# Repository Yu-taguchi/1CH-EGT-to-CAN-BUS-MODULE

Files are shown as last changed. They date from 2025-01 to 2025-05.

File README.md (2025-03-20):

# 1CH EGT TO CAN BUS モジュール

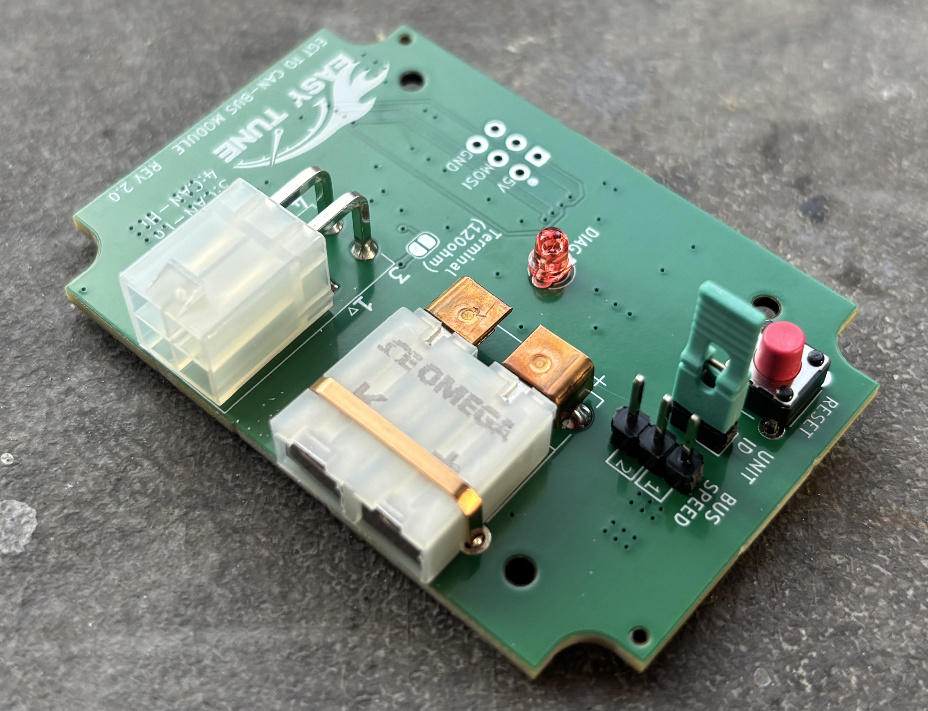
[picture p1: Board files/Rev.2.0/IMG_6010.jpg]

これは 1 チャンネル EGT ボードです。
このボードは、アフター製 エンジン コントロール ユニットと組み合わせて使用し、排気ガス温度を測定することを目的としています。
PCB は、1つの MAX31855 チップと ATMEGA328P に基づいています。
使用するセンサーは、ミニ K タイプ サーモカップル コネクタを備えた K タイプ EGT センサーである必要があります。

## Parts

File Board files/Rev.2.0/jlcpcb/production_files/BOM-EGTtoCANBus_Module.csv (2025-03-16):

Comment | Designator | Footprint | LCSC
8MHz | Y2 | Crystal_SMD_5032-2Pin_5.0x3.2mm | C115962
10uF | C4,C5,C6,C7 | C_1206_3216Metric | C13585
16MHz | Y3 | Crystal_SMD_3225-4Pin_3.2x2.5mm | C13738
ATmega328P-A | U1 | TQFP-32_7x7mm_P0.8mm | C14877
10k | R2,R3,R6 | R_0805_2012Metric | C17414
120 | R1 | R_0805_2012Metric | C17437
1k | R5,R7 | R_0805_2012Metric | C17513
22pF | C10,C12,C13,C9 | C_0805_2012Metric | C1804
1N4148WS | D2,D4 | D_SOD-323 | C2128
LED | D1,D5 | LED_D3.0mm | C2297
0.1uF | C1,C11,C2,C3,C8 | C_0805_2012Metric | C49678
MAX31855KASA | U7 | SOIC-8_3.9x4.9mm_P1.27mm | C52028
TJA1044T | U9 | SOIC-8_3.9x4.9mm_P1.27mm | C520388
MCP2515-I | U2 | TSSOP-20_4.4x6.5mm_P0.65mm | C5250735
AMS1117-3.3 | U5 | SOT-223-3_TabPin2 | C6186
AMS1117-5.0 | U3 | SOT-223-3_TabPin2 | C6187
D_Schottky | D3 | D_SOD-123 | C8598
Jumper_2_Open | JP3 | PinSocket_1x02_P2.54mm_Vertical
Jumper_3_Open | JP2 | PinSocket_1x03_P2.54mm_Vertical
SolderJumper | JP1 | SolderJumper-2_P1.3mm_Open_RoundedPad1.0x1.5mm
39-30-1040 | J2 | MOLEX_39-30-1040
PCC-SMP-V-K-5 | J3 | OMEGA_PCC-SMP-K-5
AVR-ISP-6 | J1 | IDC-Header_2x03_P2.54mm_Vertical

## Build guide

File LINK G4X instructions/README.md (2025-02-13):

# Instructions for LINK G4X
CAN設定画面を開き、下記の通りに設定すること。  
フレームデータファイル(.lcs)を用意しているので、こちらを読み込む事も可。

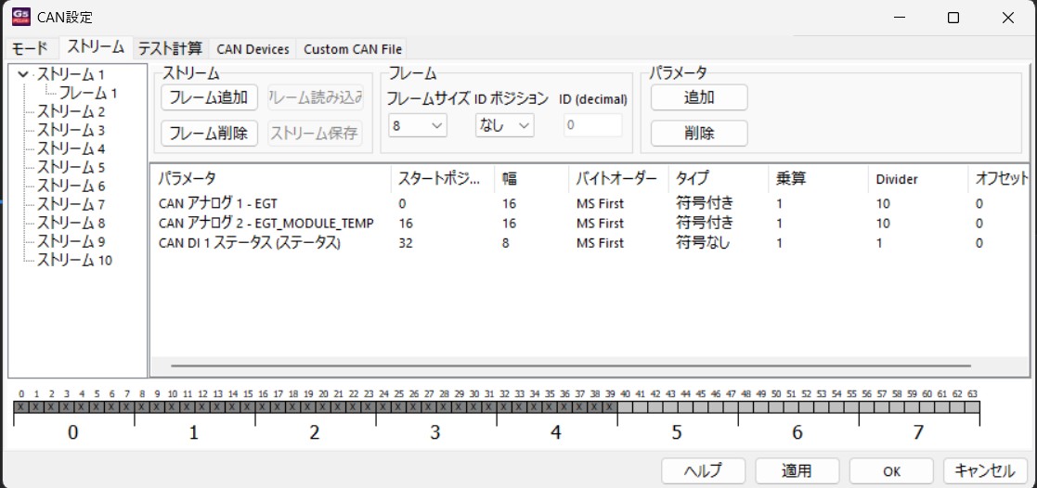
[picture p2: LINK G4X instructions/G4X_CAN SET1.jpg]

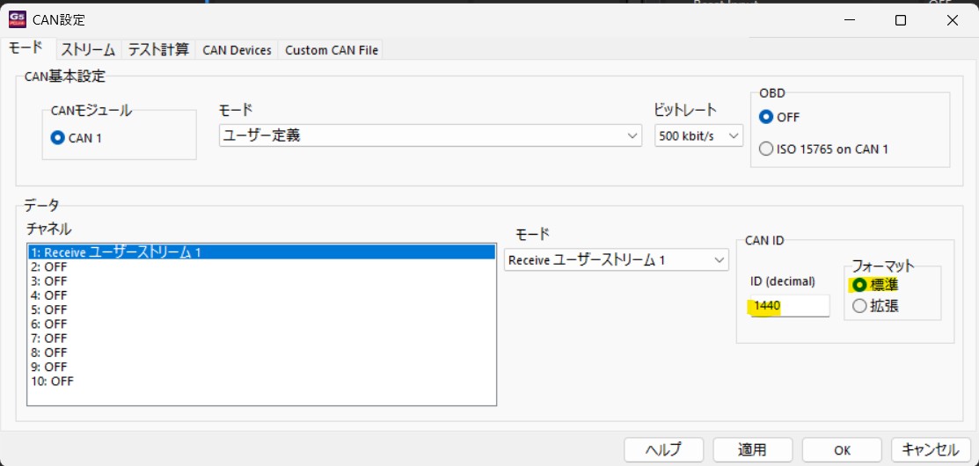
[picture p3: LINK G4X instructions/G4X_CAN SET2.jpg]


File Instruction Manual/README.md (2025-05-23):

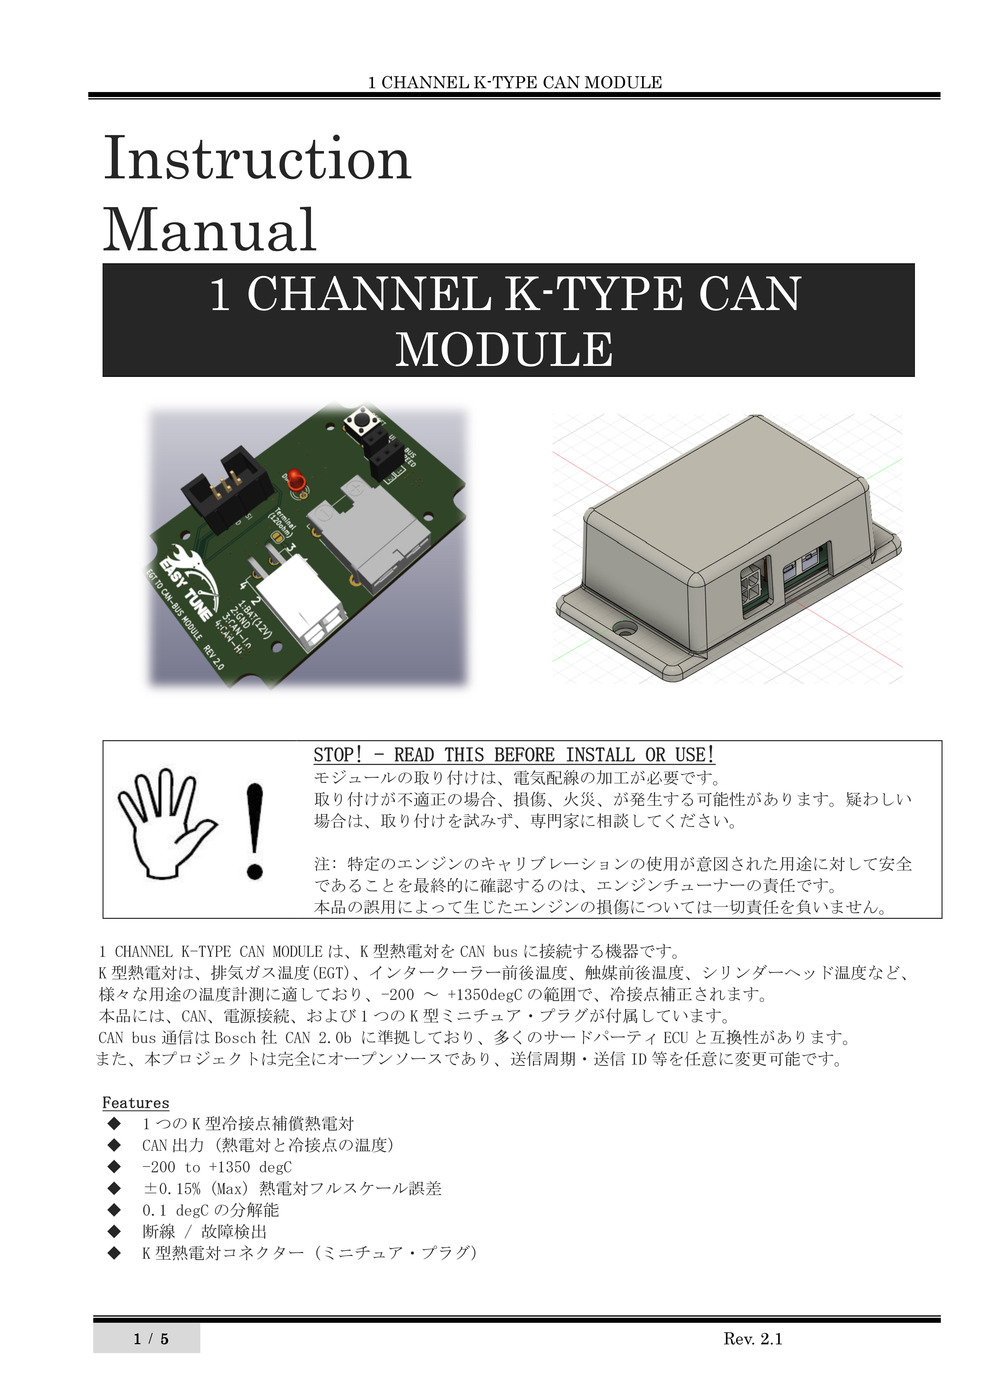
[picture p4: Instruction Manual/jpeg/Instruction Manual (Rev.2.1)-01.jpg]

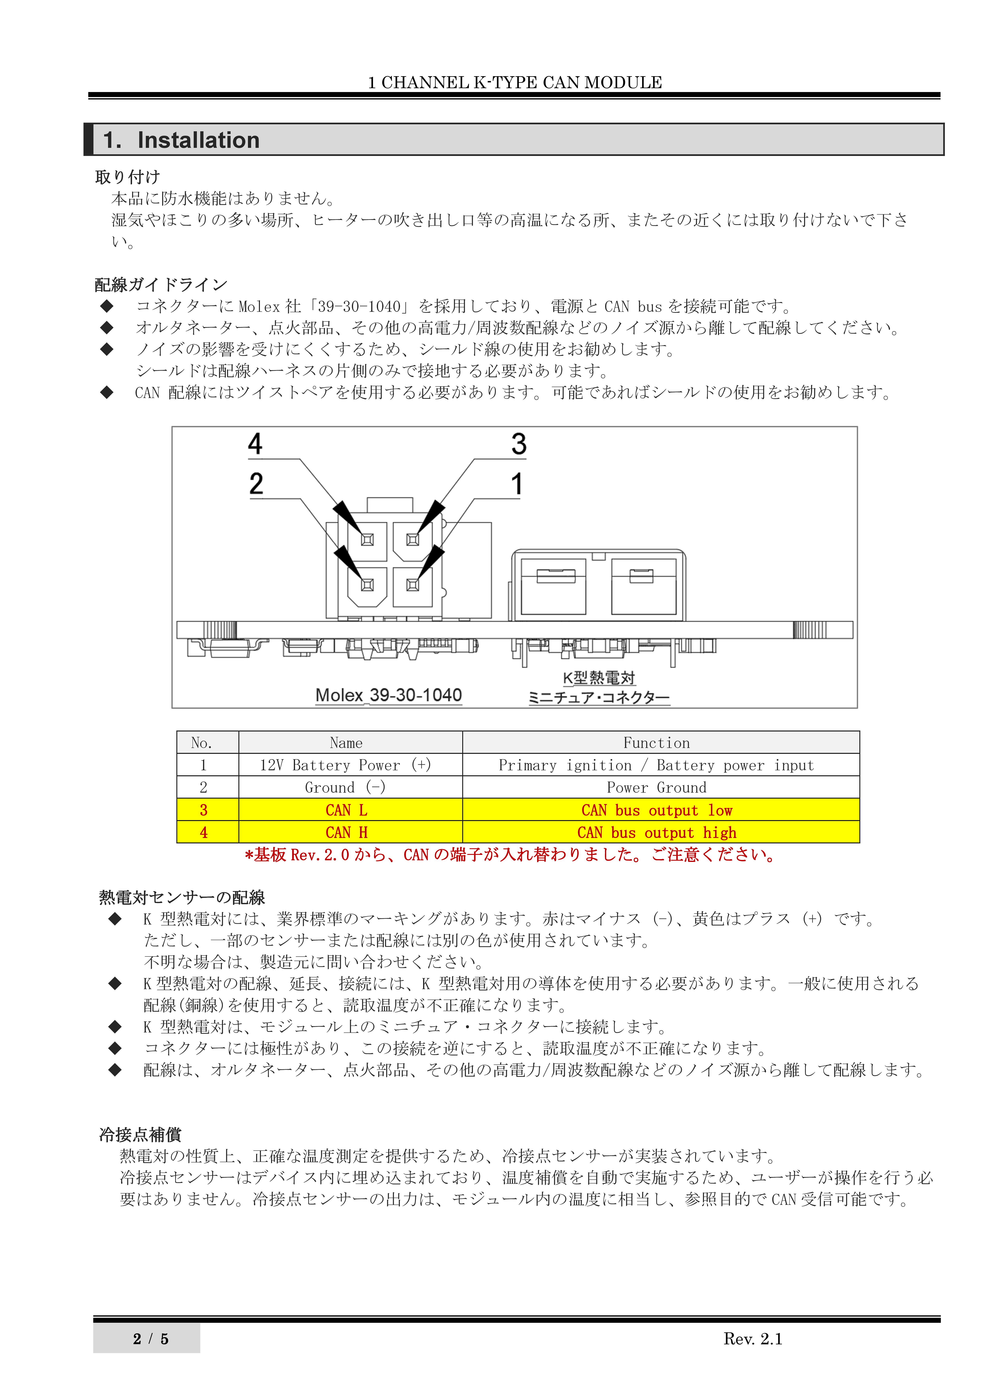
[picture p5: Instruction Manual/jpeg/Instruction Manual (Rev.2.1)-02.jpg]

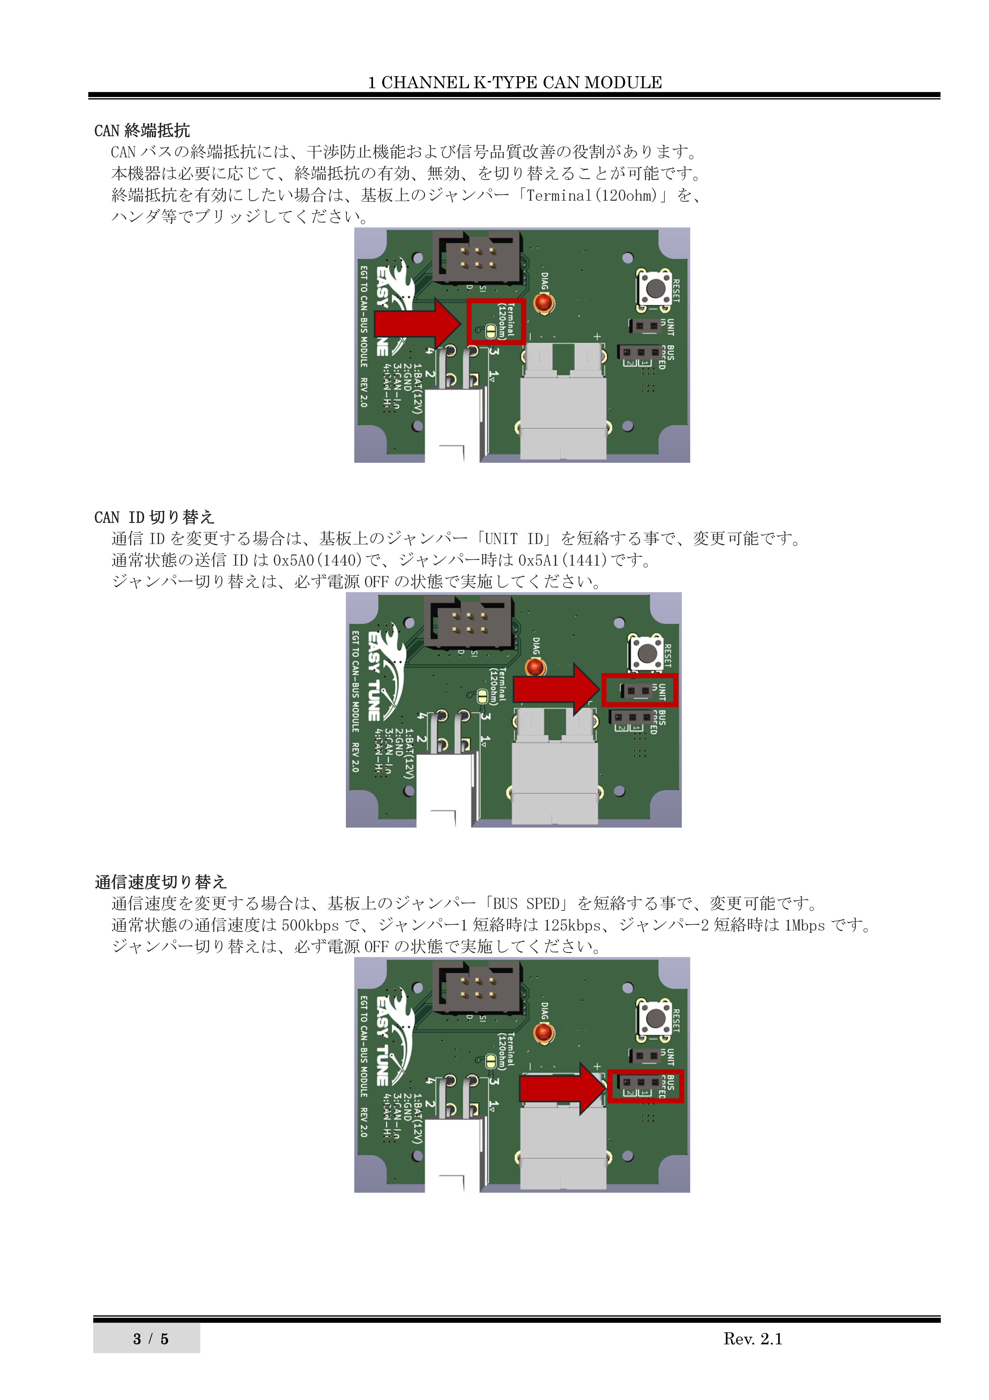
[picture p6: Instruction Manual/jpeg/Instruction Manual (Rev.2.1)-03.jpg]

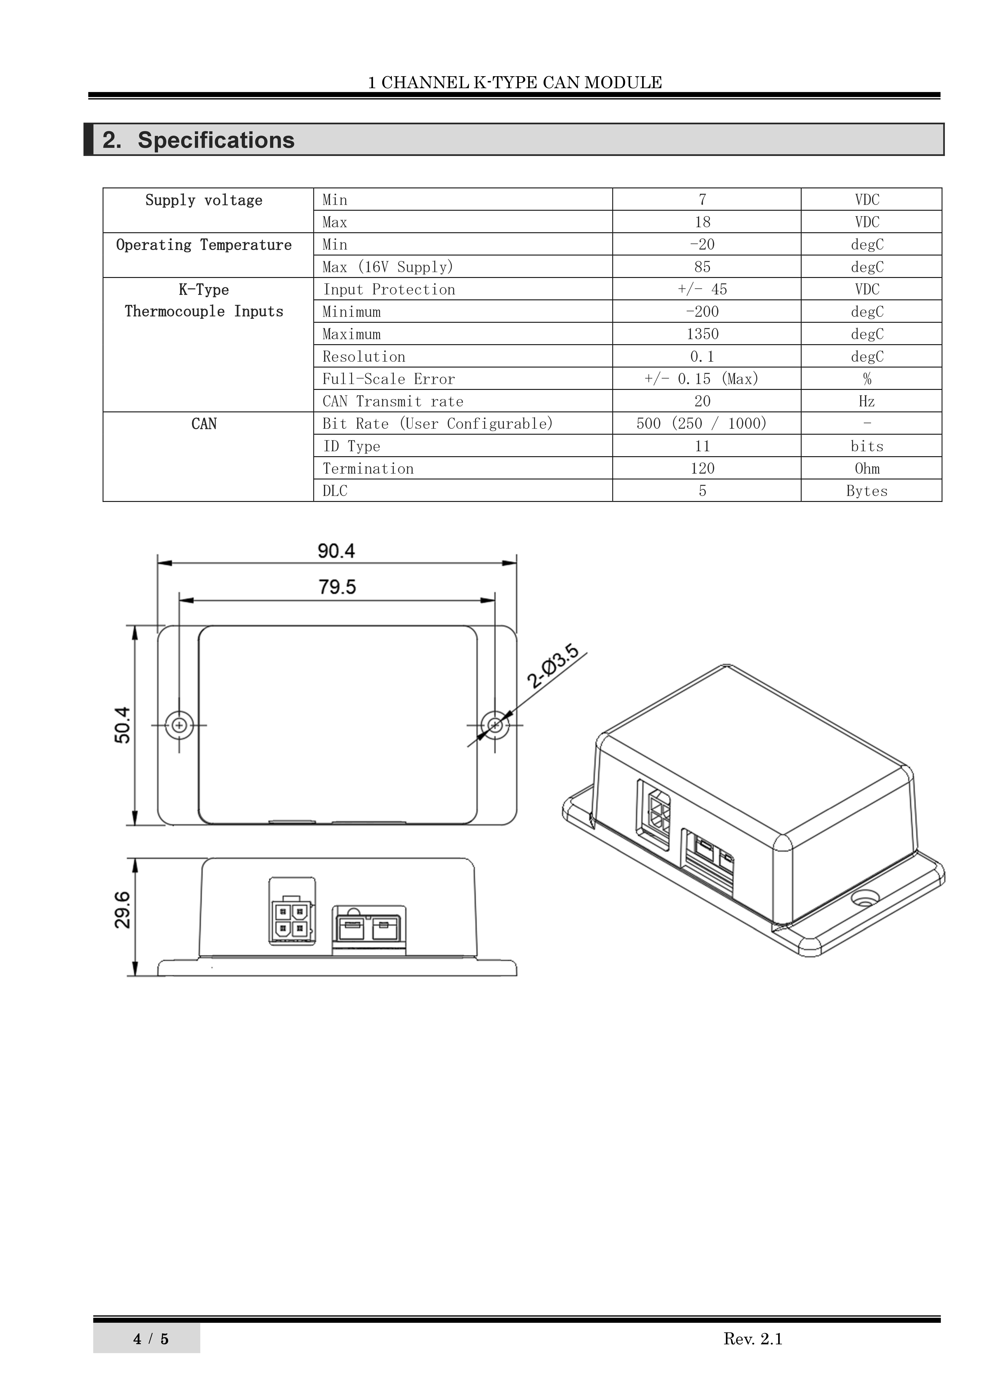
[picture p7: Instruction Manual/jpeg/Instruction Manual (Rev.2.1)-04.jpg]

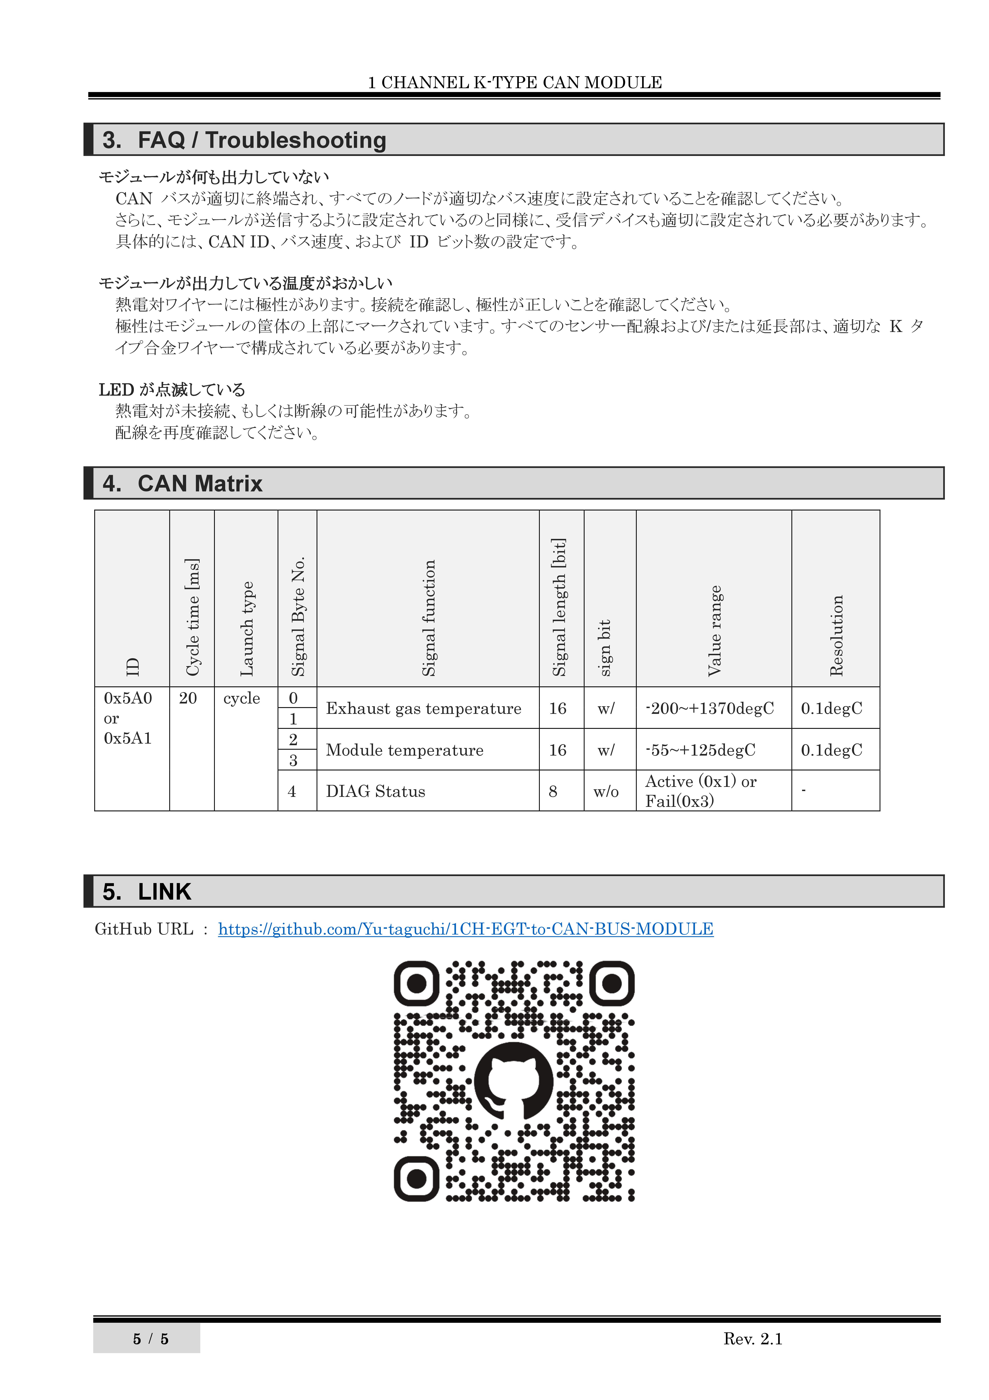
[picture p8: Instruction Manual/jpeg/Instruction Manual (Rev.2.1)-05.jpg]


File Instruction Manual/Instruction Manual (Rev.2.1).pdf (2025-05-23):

1 CHANNEL K-TYPE CAN MODULE

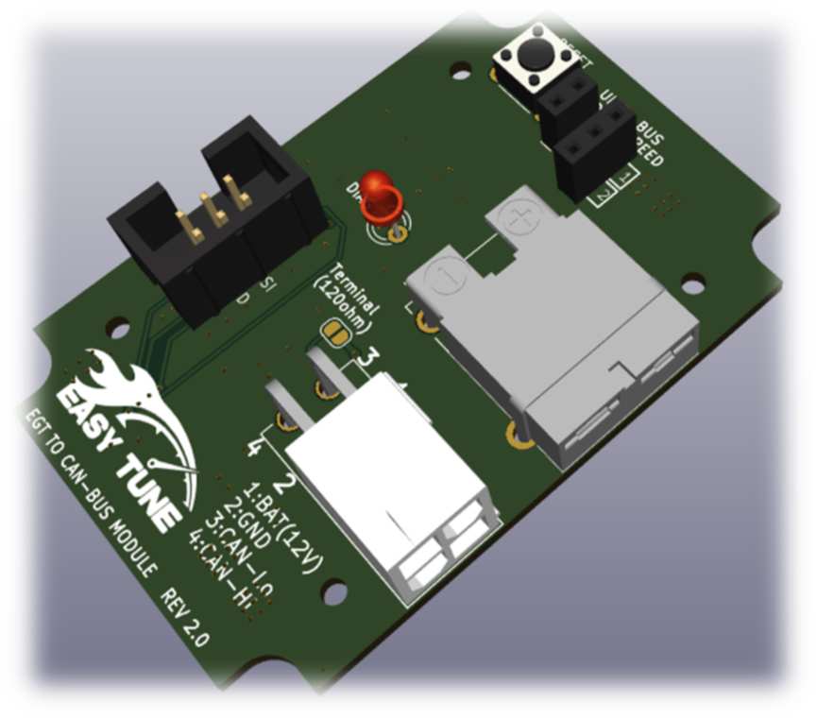
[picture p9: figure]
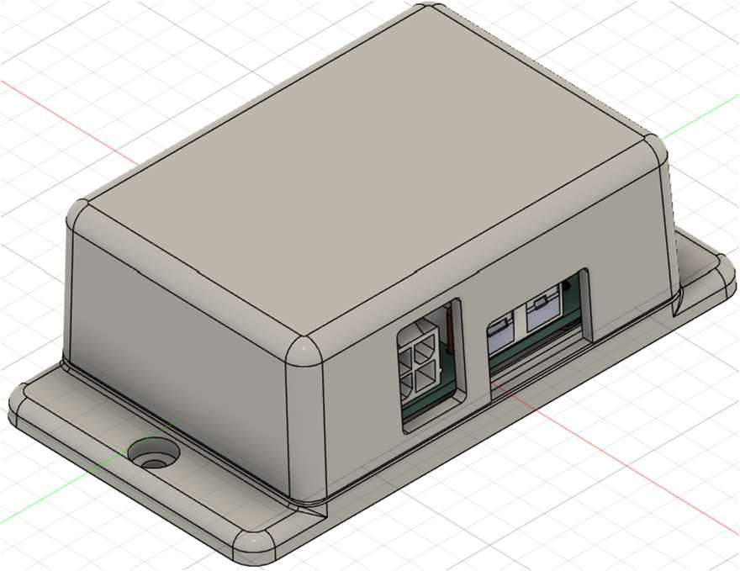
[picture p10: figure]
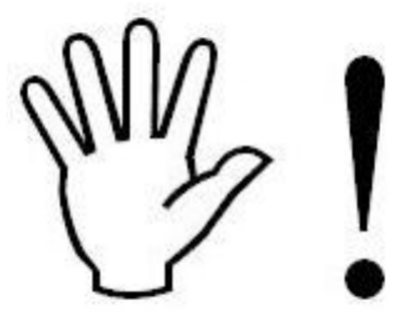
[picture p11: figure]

1 / 5 | Rev. 2.1

# Instruction Manual

# 1 CHANNEL K-TYPE CAN MODULE

### STOP! - READ THIS BEFORE INSTALL OR USE!

モジュールの取り付けは、電気配線の加工が必要です。
取り付けが不適正の場合、損傷、火災、が発生する可能性があります。疑わしい 場合は、取り付けを試みず、専門家に相談してください。

注: 特定のエンジンのキャリブレーションの使用が意図された用途に対して安全 であることを最終的に確認するのは、エンジンチューナーの責任です。 本品の誤用によって生じたエンジンの損傷については一切責任を負いません。

### 1 CHANNEL K-TYPE CAN MODULE は、K 型熱電対を CAN bus に接続する機器です。

K 型熱電対は、排気ガス温度(EGT)、インタークーラー前後温度、触媒前後温度、シリンダーヘッド温度など、 様々な用途の温度計測に適しており、-200 ～ +1350degC の範囲で、冷接点補正されます。 本品には、CAN、電源接続、および 1 つの K 型ミニチュア・プラグが付属しています。
CAN bus 通信は Bosch 社 CAN 2.0b に準拠しており、多くのサードパーティ ECU と互換性があります。 また、本プロジェクトは完全にオープンソースであり、送信周期・送信 ID 等を任意に変更可能です。

Features
- 1 つの K 型冷接点補償熱電対
- CAN 出力 (熱電対と冷接点の温度)
- -200 to +1350 degC
- ±0.15% (Max) 熱電対フルスケール誤差
- 0.1 degC の分解能
- 断線 / 故障検出
- K 型熱電対コネクター (ミニチュア・プラグ)

## 1. Installation

取り付け
本品に防水機能はありません。
湿気やほこりの多い場所、ヒーターの吹き出し口等の高温になる所、またその近くには取り付けないで下さ い。

配線ガイドライン
- コネクターに Molex 社「39-30-1040」を採用しており、電源と CAN bus を接続可能です。
- オルタネーター、点火部品、その他の高電力/周波数配線などのノイズ源から離して配線してください。
- ノイズの影響を受けにくくするため、シールド線の使用をお勧めします。 シールドは配線ハーネスの片側のみで接地する必要があります。
- CAN 配線にはツイストペアを使用する必要があります。可能であればシールドの使用をお勧めします。

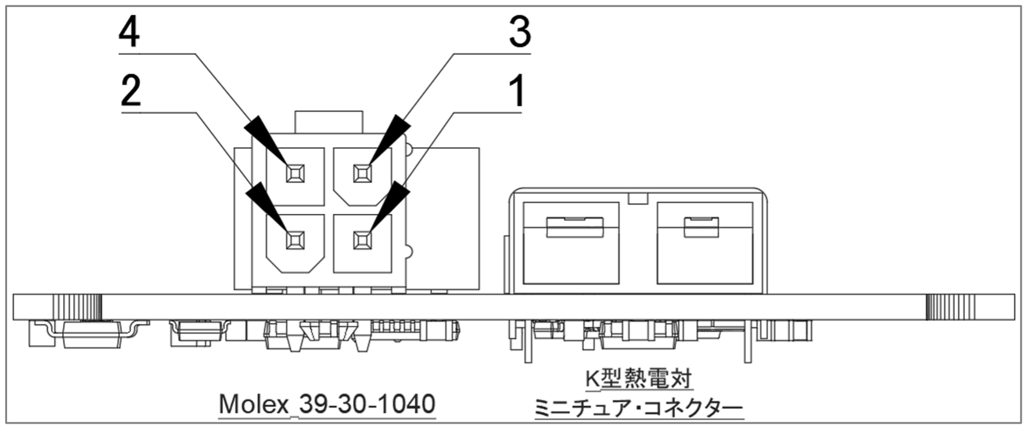
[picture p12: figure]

No. | Name | Function
1 | 12V Battery Power (+) | Primary ignition / Battery power input
2 | Ground (-) | Power Ground
3 | CAN L | CAN bus output low
4 | CAN H | CAN bus output high
*基板 Rev.2.0 から、CAN の端子が入れ替わりました。ご注意ください。

熱電対センサーの配線
- K 型熱電対には、業界標準のマーキングがあります。赤はマイナス (-)、黄色はプラス (+) です。 ただし、一部のセンサーまたは配線には別の色が使用されています。 不明な場合は、製造元に問い合わせください。
- K 型熱電対の配線、延長、接続には、K 型熱電対用の導体を使用する必要があります。一般に使用される 配線(銅線)を使用すると、読取温度が不正確になります。
- K 型熱電対は、モジュール上のミニチュア・コネクターに接続します。
- コネクターには極性があり、この接続を逆にすると、読取温度が不正確になります。
- 配線は、オルタネーター、点火部品、その他の高電力/周波数配線などのノイズ源から離して配線します。

冷接点補償
熱電対の性質上、正確な温度測定を提供するため、冷接点センサーが実装されています。 冷接点センサーはデバイス内に埋め込まれており、温度補償を自動で実施するため、ユーザーが操作を行う必 要はありません。冷接点センサーの出力は、モジュール内の温度に相当し、参照目的で CAN 受信可能です。

CAN 終端抵抗
CAN バスの終端抵抗には、干渉防止機能および信号品質改善の役割があります。 本機器は必要に応じて、終端抵抗の有効、無効、を切り替えることが可能です。 終端抵抗を有効にしたい場合は、基板上のジャンパー「Terminal(120ohm)」を、 ハンダ等でブリッジしてください。

CAN ID 切り替え

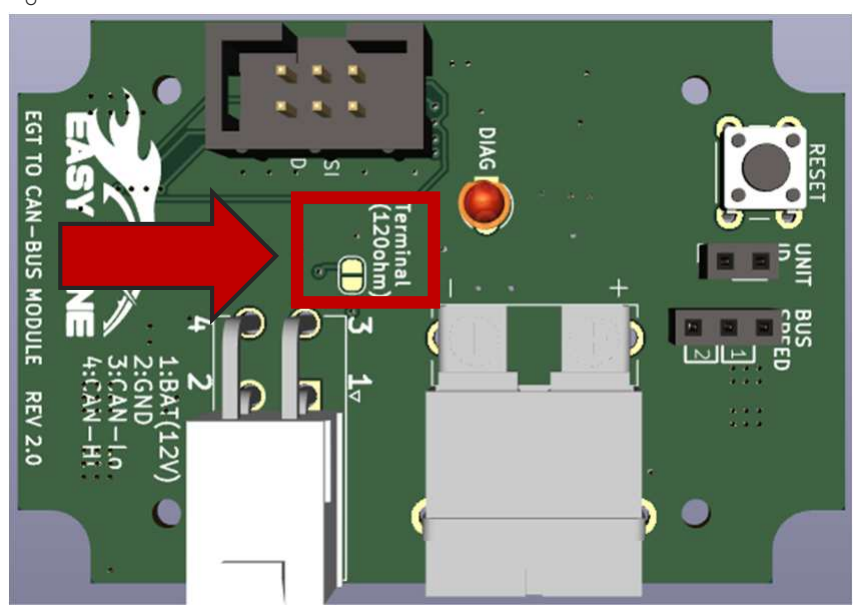
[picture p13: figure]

通信 ID を変更する場合は、基板上のジャンパー「UNIT ID」を短絡する事で、変更可能です。 通常状態の送信 ID は 0x5A0(1440)で、ジャンパー時は 0x5A1(1441)です。 ジャンパー切り替えは、必ず電源 OFF の状態で実施してください。

通信速度切り替え

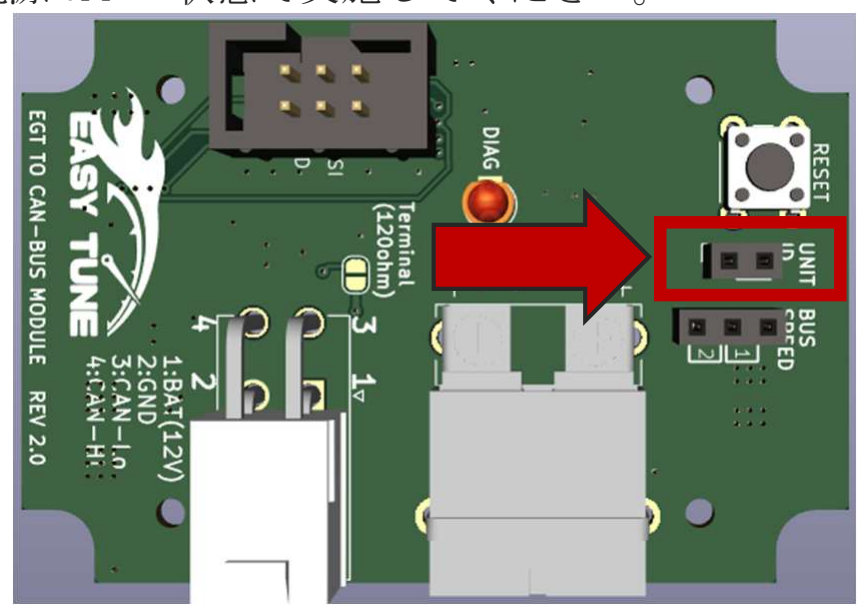
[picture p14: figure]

通信速度を変更する場合は、基板上のジャンパー「BUS SPED」を短絡する事で、変更可能です。 通常状態の通信速度は 500kbps で、ジャンパー1 短絡時は 125kbps、ジャンパー2 短絡時は 1Mbps です。 ジャンパー切り替えは、必ず電源 OFF の状態で実施してください。

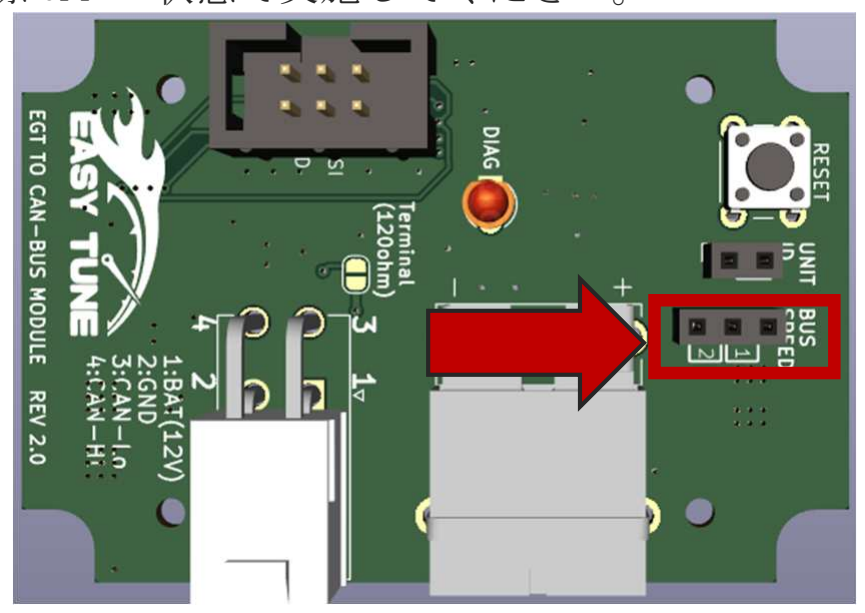
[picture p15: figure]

## 2. Specifications

Supply voltage | Min | 7 | VDC
| Max | 18 | VDC
Operating Temperature | Min | -20 | degC
| Max (16V Supply) | 85 | degC
K-Type Thermocouple Inputs | Input Protection | +/- 45 | VDC
| Minimum | -200 | degC
| Maximum | 1350 | degC
| Resolution | 0.1 | degC
| Full-Scale Error | +/- 0.15 (Max) | %
| CAN Transmit rate | 20 | Hz
CAN | Bit Rate (User Configurable) | 500 (250 / 1000) | -
| ID Type | 11 | bits
| Termination | 120 | Ohm
| DLC | 5 | Bytes

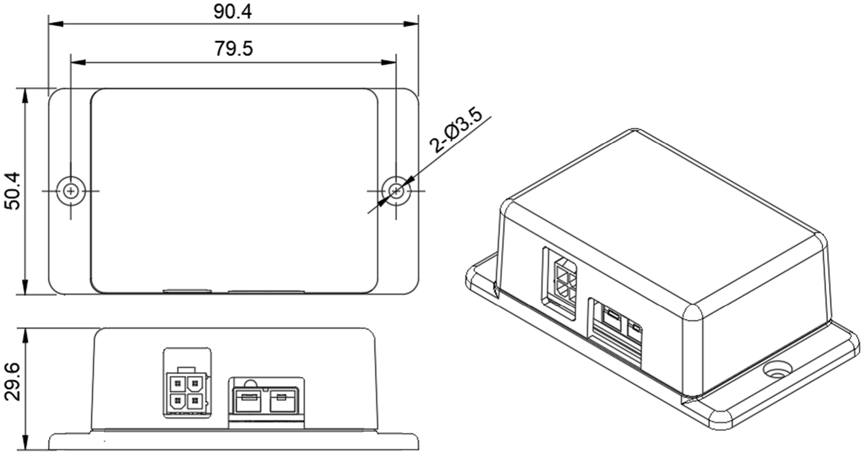
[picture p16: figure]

## 3. FAQ / Troubleshooting

モジュールが何も出力していない
CAN バスが適切に終端され、すべてのノードが適切なバス速度に設定されていることを確認してください。 さらに、モジュールが送信するように設定されているのと同様に、受信デバイスも適切に設定されている必要があります。 具体的には、CAN ID、バス速度、および ID ビット数の設定です。

モジュールが出力している温度がおかしい
熱電対ワイヤーには極性があります。接続を確認し、極性が正しいことを確認してください。 極性はモジュールの筐体の上部にマークされています。すべてのセンサー配線および/または延長部は、適切な K タ イプ合金ワイヤーで構成されている必要があります。

LED が点滅している
熱電対が未接続、もしくは断線の可能性があります。
配線を再度確認してください。
4. CAN Matrix ID | Cycle time [ms] | Launch type
0x5A0 or 0x5A1 | 20 | cycle | 0 | Exhaust gas temperature | 16 | w/ | -200~+1370degC | 0.1degC 1
| | | 2 | Module temperature | 16 | w/ | -55~+125degC | 0.1degC 3
| | | 4 | DIAG Status | 8 | w/o | Active (0x1) or Fail(0x3) | -

Signal Byte No.
Signal function

Signal length [bit]

sign bit

Value range
Resolution

## 5. LINK

GitHub URL ： https://github.com/Yu-taguchi/1CH-EGT-to-CAN-BUS-MODULE

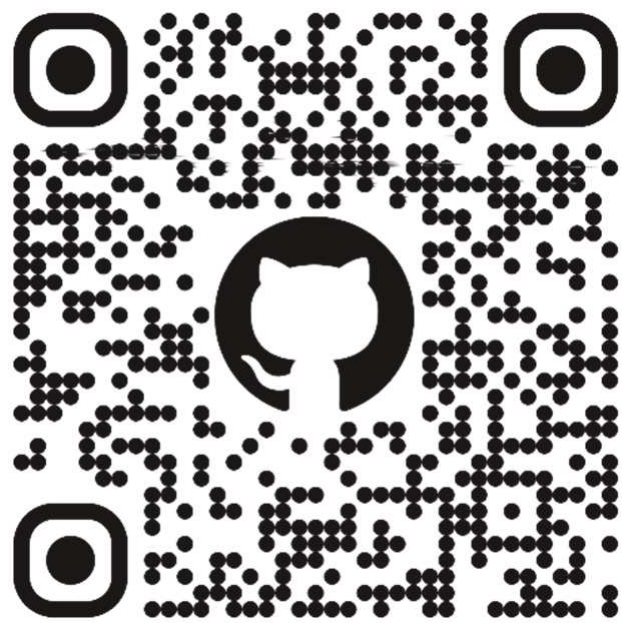
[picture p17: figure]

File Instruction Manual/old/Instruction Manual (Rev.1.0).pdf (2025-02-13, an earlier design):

1 CHANNEL K-TYPE CAN MODULE

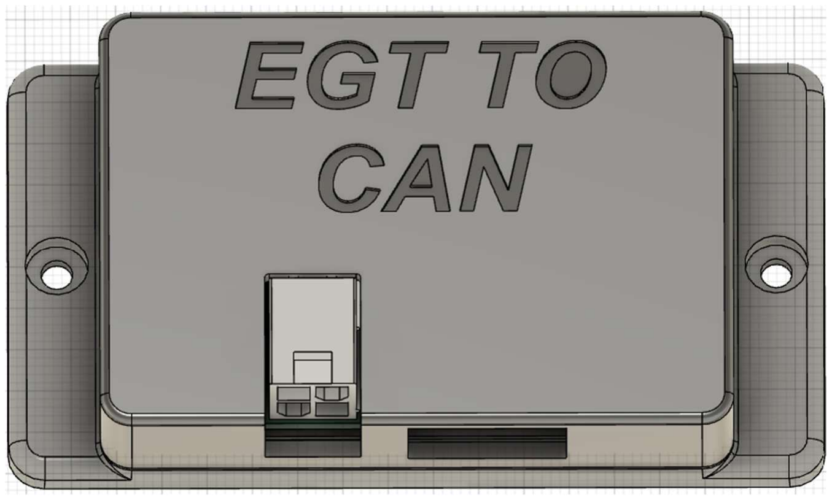
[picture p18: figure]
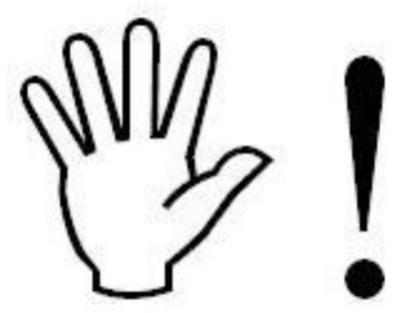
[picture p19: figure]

1 / 5 | Rev. 1.0

# Instruction Manual

# 1 CHANNEL K-TYPE CAN MODULE

### STOP! - READ THIS BEFORE INSTALL OR USE!

モジュールの取り付けは、電気配線の加工が必要です。
取り付けが不適正の場合、損傷、火災、が発生する可能性があります。疑わしい 場合は、取り付けを試みず、専門家に相談してください。

注: 特定のエンジンのキャリブレーションの使用が意図された用途に対して安全 であることを最終的に確認するのは、エンジンチューナーの責任です。 本品の誤用によって生じたエンジンの損傷については一切責任を負いません。

### 1 CHANNEL K-TYPE CAN MODULE は、K 型熱電対を CAN bus に接続する機器です。

K 型熱電対は、排気ガス温度(EGT)、インタークーラー前後温度、触媒前後温度、シリンダーヘッド温度など、 様々な用途の温度計測に適しており、-200 ～ +1350degC の範囲で、冷接点補正されます。 本品には、CAN、電源接続、および 1 つの K 型ミニチュア・プラグが付属しています。
CAN bus 通信は Bosch 社 CAN 2.0b に準拠しており、多くのサードパーティ ECU と互換性があります。 また、本プロジェクトは完全にオープンソースであり、送信周期・送信 ID 等を任意に変更可能です。

Features
- 1 つの K 型冷接点補償熱電対
- CAN 出力 (熱電対と冷接点の温度)
- -200 to +1350 degC
- ±0.15% (Max) 熱電対フルスケール誤差
- 0.1 degC の分解能
- 断線 / 故障検出
- K 型熱電対コネクター (ミニチュア・プラグ)

## 1. Installation

取り付け
本品に防水機能はありません。
湿気やほこりの多い場所、ヒーターの吹き出し口等の高温になる所、またその近くには取り付けないで下さ い。

配線ガイドライン
- コネクターに Molex 社「39-30-1040」を採用しており、電源と CAN bus を接続可能です。
- オルタネーター、点火部品、その他の高電力/周波数配線などのノイズ源から離して配線してください。
- ノイズの影響を受けにくくするため、シールド線の使用をお勧めします。 シールドは配線ハーネスの片側のみで接地する必要があります。
- CAN 配線にはツイストペアを使用する必要があります。可能であればシールドの使用をお勧めします。

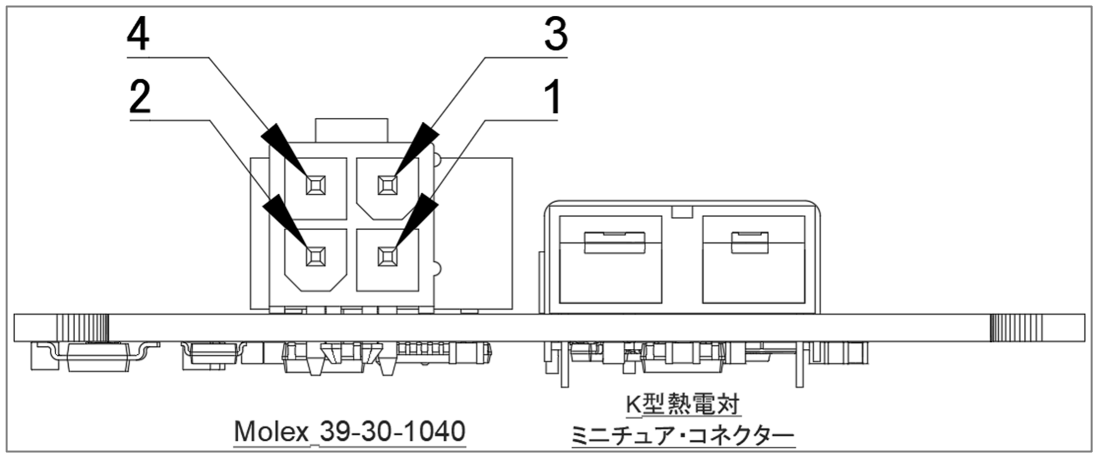
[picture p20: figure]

No. | Name | Function
1 | 12V Battery Power (+) | Primary ignition / Battery power input
2 | Ground (-) | Power Ground
3 | CAN H | CAN bus output high
4 | CAN L | CAN bus output low

熱電対センサーの配線
- K 型熱電対には、業界標準のマーキングがあります。赤はマイナス (-)、黄色はプラス (+) です。 ただし、一部のセンサーまたは配線には別の色が使用されています。 不明な場合は、製造元に問い合わせください。
- K 型熱電対の配線、延長、接続には、K 型熱電対用の導体を使用する必要があります。一般に使用される 配線(銅線)を使用すると、読取温度が不正確になります。
- K 型熱電対は、モジュール上のミニチュア・コネクターに接続します。
- コネクターには極性があり、この接続を逆にすると、読取温度が不正確になります。
- 配線は、オルタネーター、点火部品、その他の高電力/周波数配線などのノイズ源から離して配線します。

冷接点補償
熱電対の性質上、正確な温度測定を提供するため、冷接点センサーが実装されています。 冷接点センサーはデバイス内に埋め込まれており、温度補償を自動で実施するため、ユーザーが操作を行う必 要はありません。冷接点センサーの出力は、モジュール内の温度に相当し、参照目的で CAN 受信可能です。

CAN 終端抵抗
CAN バスの終端抵抗には、干渉防止機能および信号品質改善の役割があります。 本機器は必要に応じて、終端抵抗の有効、無効、を切り替えることが可能です。 終端抵抗を有効にしたい場合は、基板上のジャンパー「Terminal(120ohm)」を、 ハンダ等でブリッジしてください。

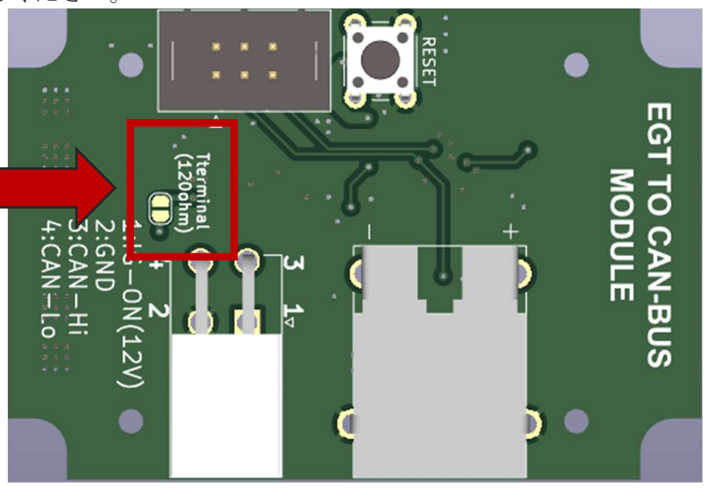
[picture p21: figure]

## 2. Specifications

Supply voltage | Min | 7 | VDC
| Max | 18 | VDC
Operating Temperature | Min | -20 | degC
| Max (16V Supply) | 85 | degC
K-Type Thermocouple Inputs | Input Protection | +/- 45 | VDC
| Minimum | -200 | degC
| Maximum | 1350 | degC
| Resolution | 0.1 | degC
| Full-Scale Error | +/- 0.15 (Max) | %
| CAN Transmit rate | 20 | Hz
CAN | Bit Rate (User Configurable) | 500 (250 / 1000) | -
| ID Type | 11 | bits
| Termination | 120 | Ohm
| DLC | 5 | Bytes

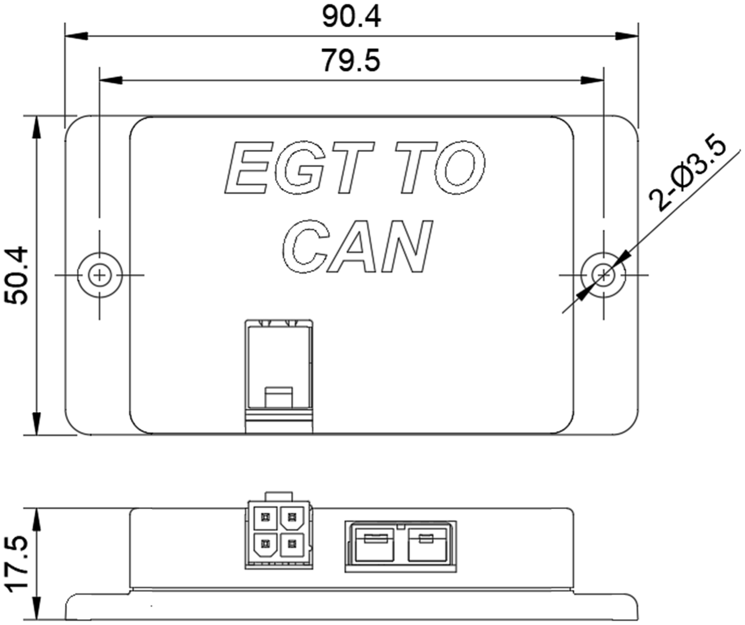
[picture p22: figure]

## 3. FAQ / Troubleshooting

モジュールが何も出力していない
CAN バスが適切に終端され、すべてのノードが適切なバス速度に設定されていることを確認してください。 さらに、モジュールが送信するように設定されているのと同様に、受信デバイスも適切に設定されている必要があります。 具体的には、CAN ID、バス速度、および ID ビット数の設定です。

モジュールが出力している温度がおかしい
熱電対ワイヤーには極性があります。接続を確認し、極性が正しいことを確認してください。 極性はモジュールの筐体の上部にマークされています。すべてのセンサー配線および/または延長部は、適切な K タ イプ合金ワイヤーで構成されている必要があります。
4. CAN Matrix ID | Cycle time [ms] | Launch type
0x5A0 | 20 | cycle | 0 | Exhaust gas temperature | 16 | w/ | -200~+1370degC | 0.1degC 1
| | | 2 | Module temperature | 16 | w/ | -55~+125degC | 0.1degC 3
| | | 4 | DIAG Status | 8 | w/o | Active (0x1) or Fail(0x3) | -

Signal Byte No.
Signal function

Signal length [bit]

sign bit

Value range
Resolution

## 5. LINK

GitHub URL ： https://github.com/Yu-taguchi/1CH-EGT-to-CAN-BUS-MODULE

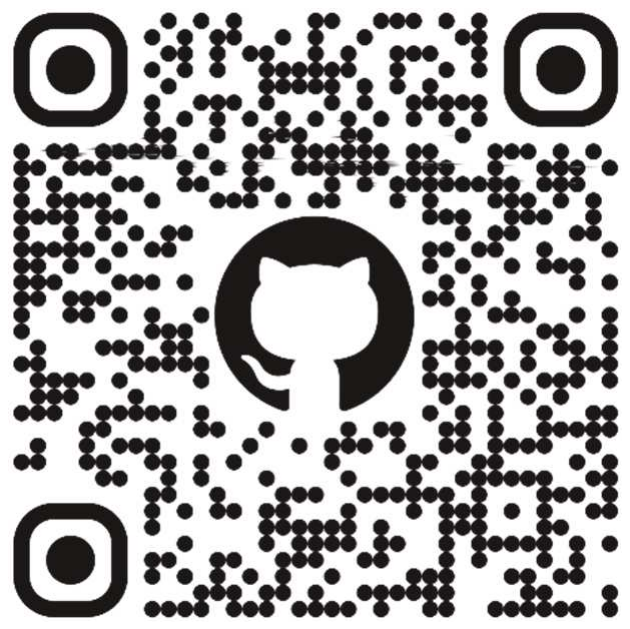
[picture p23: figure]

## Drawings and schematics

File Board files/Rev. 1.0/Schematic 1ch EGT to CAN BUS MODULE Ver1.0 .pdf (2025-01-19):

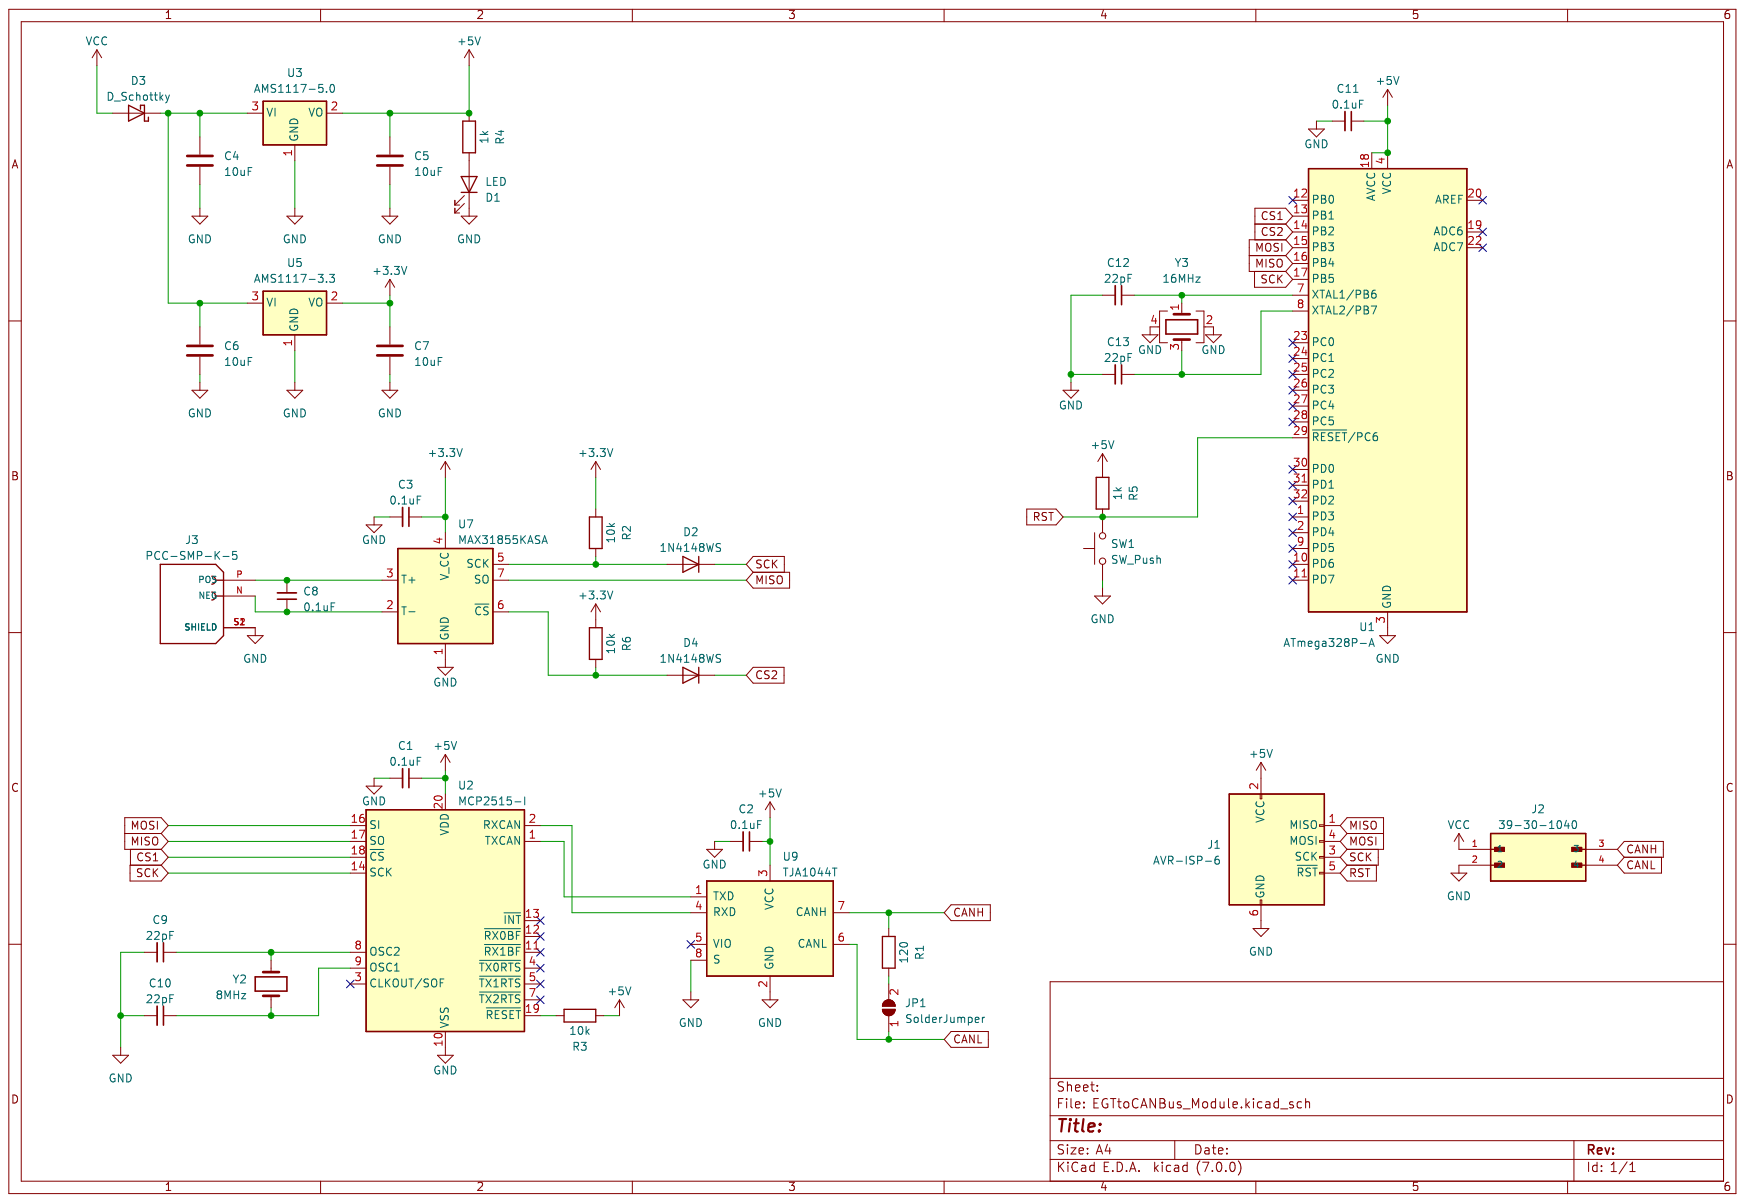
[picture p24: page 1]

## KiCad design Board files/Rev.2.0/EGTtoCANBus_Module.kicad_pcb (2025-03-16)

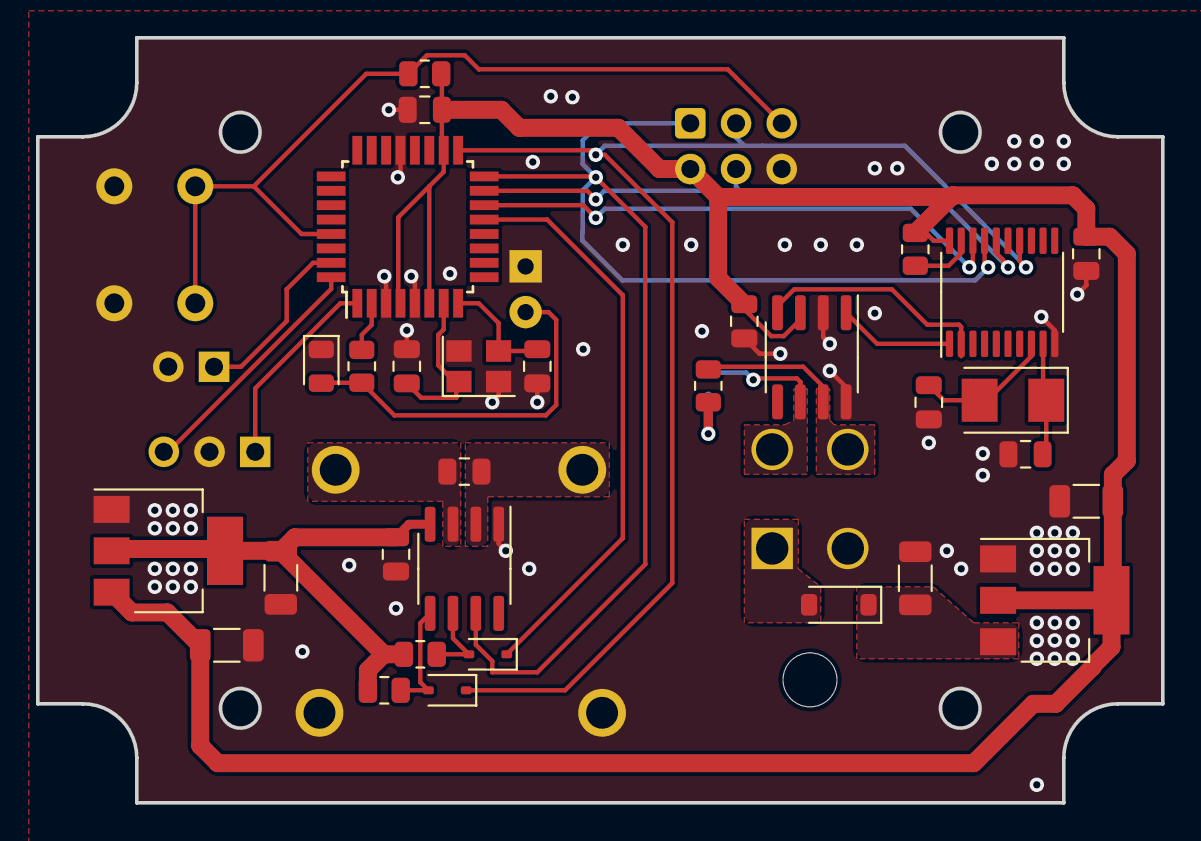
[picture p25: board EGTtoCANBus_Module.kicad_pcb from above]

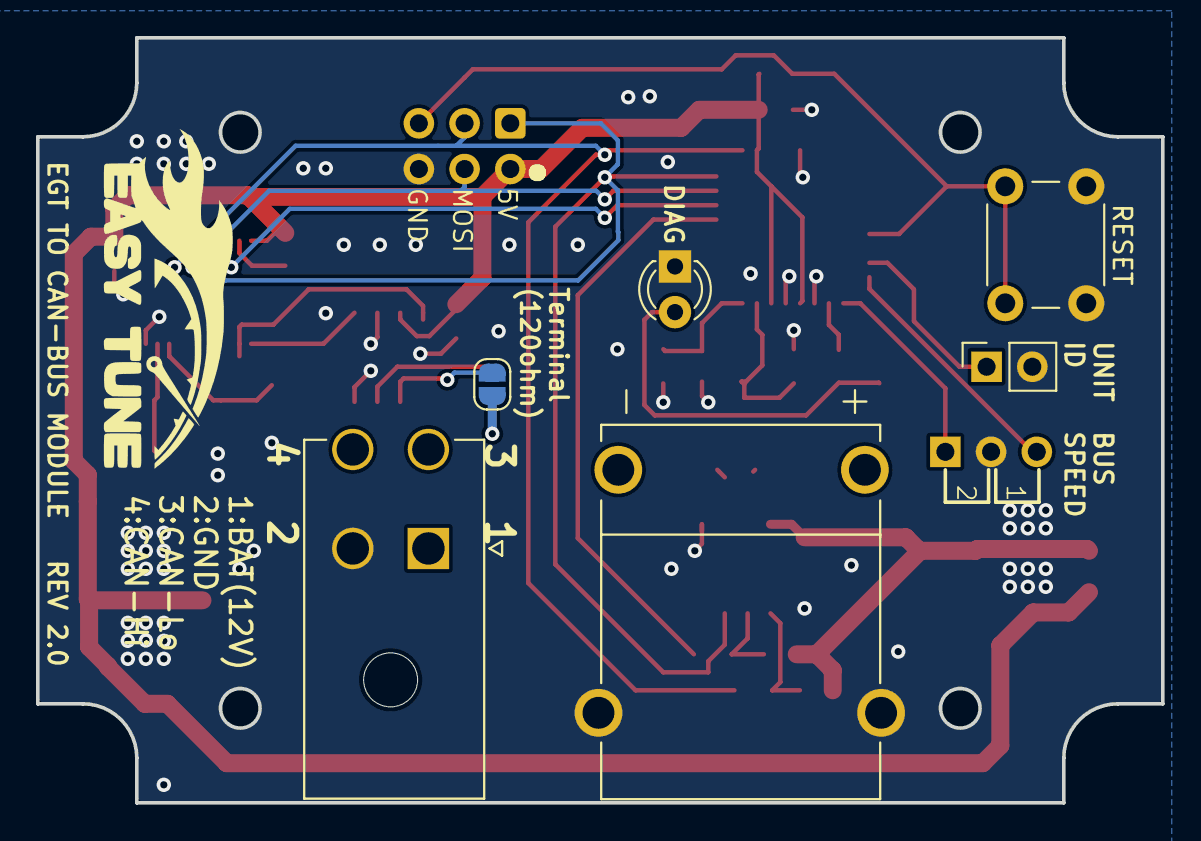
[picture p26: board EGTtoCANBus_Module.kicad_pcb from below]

Board: 2 copper layers, 62.5 x 42.5 mm, 39 parts (8 on the bottom side), 30 nets.

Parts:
C1, C2, C3, C8, C11: 0.1uF; C_0805_2012Metric
C4, C5, C6, C7: 10uF; C_1206_3216Metric
C9, C10, C12, C13: 22pF; C_0805_2012Metric
D1: LED; LED_D3.0mm
D2, D4: 1N4148WS; D_SOD-323
D3: D_Schottky; D_SOD-123
D5: LED; LED_0805_2012Metric
J1: AVR-ISP-6; IDC-Header_2x03_P2.54mm_Vertical
J2: 39-30-1040; MOLEX_39-30-1040
J3: PCC-SMP-V-K-5; OMEGA_PCC-SMP-K-5
JP1: SolderJumper; SolderJumper-2_P1.3mm_Open_RoundedPad1.0x1.5mm
JP2: Jumper_3_Open; PinSocket_1x03_P2.54mm_Vertical
JP3: Jumper_2_Open; PinSocket_1x02_P2.54mm_Vertical
R1: 120; R_0805_2012Metric
R2, R3, R6: 10k; R_0805_2012Metric
R5, R7: 1k; R_0805_2012Metric
RESET: SW_Push; SW_PUSH_6mm
U1: ATmega328P-A; TQFP-32_7x7mm_P0.8mm
U2: MCP2515-I; TSSOP-20_4.4x6.5mm_P0.65mm
U3: AMS1117-5.0; SOT-223-3_TabPin2
U5: AMS1117-3.3; SOT-223-3_TabPin2
U7: MAX31855KASA; SOIC-8_3.9x4.9mm_P1.27mm
U9: TJA1044T; SOIC-8_3.9x4.9mm_P1.27mm
Y2: 8MHz; Crystal_SMD_5032-2Pin_5.0x3.2mm
Y3: 16MHz; Crystal_SMD_3225-4Pin_3.2x2.5mm

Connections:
+3.3V: C3.1, C7.1, R2.1, R6.1, U5.2 (VO), U7.4 (V_CC)
+5V: C1.1, C2.1, C5.1, C6.1, C11.1, J1.2 (VCC), R3.1, R5.1, U1.4 (VCC), U1.6 (VCC), U1.18 (AVCC), U2.20 (VDD), U3.2 (VO), U5.3 (VI), U9.3 (VCC)
CANH: J2.4, R1.1, U9.7 (CANH)
CANL: J2.3, JP1.1 (A), U9.6 (CANL)
CS1: U1.14 (PB2), U2.18 (~CS)
CS2: D4.1 (K), U1.13 (PB1)
GND: C1.2, C2.2, C3.2, C4.2, C5.2, C6.2, C7.2, C9.2, C10.2, C11.2, C12.2, C13.2, D1.1 (K), D5.1 (K), J1.6 (GND), J2.2, J3.S1 (SHIELD), J3.S2 (SHIELD), JP2.2 (C), JP3.2 (B), RESET.1, U1.3 (GND), U1.5 (GND), U1.21 (GND), U2.10 (VSS), U3.1 (GND), U5.1 (GND), U7.1 (GND), U9.2 (GND), U9.8 (S), Y3.2, Y3.4
MISO: J1.1 (MISO), U1.16 (PB4), U2.17 (SO), U7.7 (SO)
MOSI: J1.4 (MOSI), U1.15 (PB3), U2.16 (SI)
unnamed: D1.2 (A), D5.2 (A), R7.2
unnamed: D2.2 (A), R2.2, U7.5 (SCK)
unnamed: C4.1, D3.1 (K), U3.3 (VI)
unnamed: D4.2 (A), R6.2, U7.6 (~CS)
unnamed: C8.1, J3.N (NEG), U7.2 (T-)
unnamed: C8.2, J3.P (POS), U7.3 (T+)
unnamed: JP1.2 (B), R1.2
unnamed: JP2.1 (A), U1.1 (PD3)
unnamed: JP2.3 (B), U1.32 (PD2)
unnamed: JP3.1 (A), U1.31 (PD1)
unnamed: R7.1, U1.2 (PD4)
unnamed: C12.1, U1.7 (XTAL1/PB6), Y3.1
unnamed: C13.1, U1.8 (XTAL2/PB7), Y3.3
unnamed: C10.1, U2.9 (OSC1), Y2.1
unnamed: C9.1, U2.8 (OSC2), Y2.2
unnamed: U2.2 (RXCAN), U9.4 (RXD)
unnamed: U2.1 (TXCAN), U9.1 (TXD)
unnamed: R3.2, U2.19 (~RESET)
RST: J1.5 (~RST), R5.2, RESET.2, U1.29 (~RESET/PC6)
SCK: D2.1 (K), J1.3 (SCK), U1.17 (PB5), U2.14 (SCK)
VCC: D3.2 (A), J2.1
